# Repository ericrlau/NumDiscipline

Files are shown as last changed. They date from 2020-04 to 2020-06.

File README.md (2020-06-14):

# #DISCIPLINE (aka NumDiscipline)

A modified version of the great looking Discipline through hole keyboard design by coseyfannitutti to add numpad. 

## Modifications from original Discipline 

- Add numpad on right.
- Move arrow keys 0.25U down and right, similar to 1800 layout. 
- Adjust component layout on top of board, moving ATMega and buttons to the right, adding in more diodes in center. 
- Removed ~, Delete, Page Up, Page Down keys. These will be on alternate layer. 
- Created Digikey version of BOM, found here: https://octopart.com/bom-tool/AgAHKWUi

## ToDo 
- Adjust acrylic foot design to be wider, it looks a little thin. 
- add Via support
- Next order of PCBs: 
	- Adjust #DISCIPLINE logo in space bar area so that it doesn't overlap stablaizer. [Image](./images/knownIssues/Logoplacement.jpg)
	- Omit job number silk screen from vendor.[Plate](./images/knownIssues/plate.jpg) [Main](./images/knownIssues/jobNumMain.jpg) [Bottom](./images/knownIssues/jobNumBottom.jpg) 
	- Improve surface finish on black solder mask, some dark spots. [Image](./images/knownIssues/surfaceFinish.jpg) 
	- Remove drills from FR4 switch plate. [Image](./images/knownIssues/plate.jpg)

## Images

#### Prototype Build
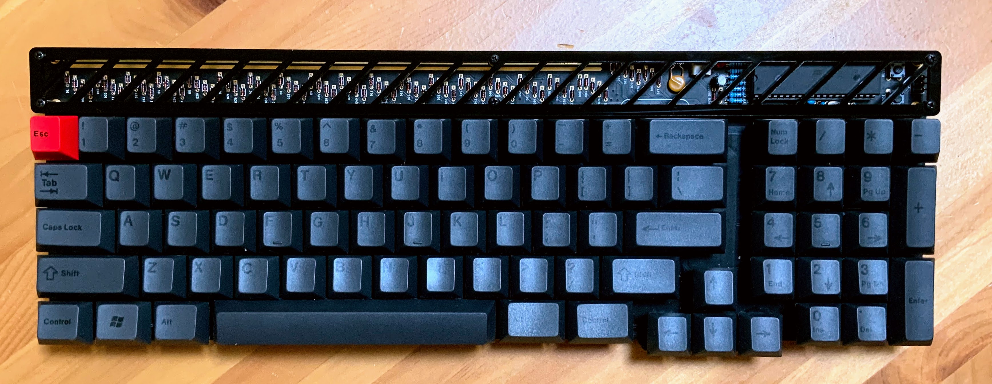
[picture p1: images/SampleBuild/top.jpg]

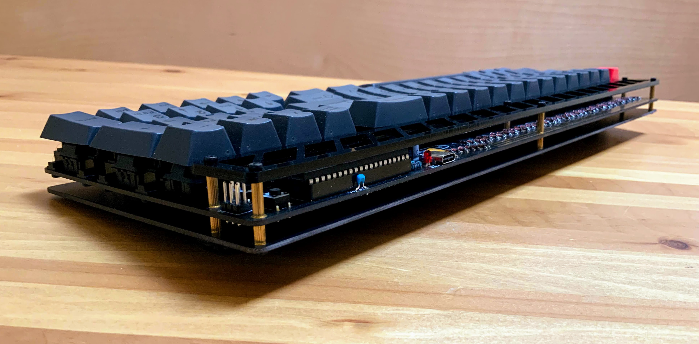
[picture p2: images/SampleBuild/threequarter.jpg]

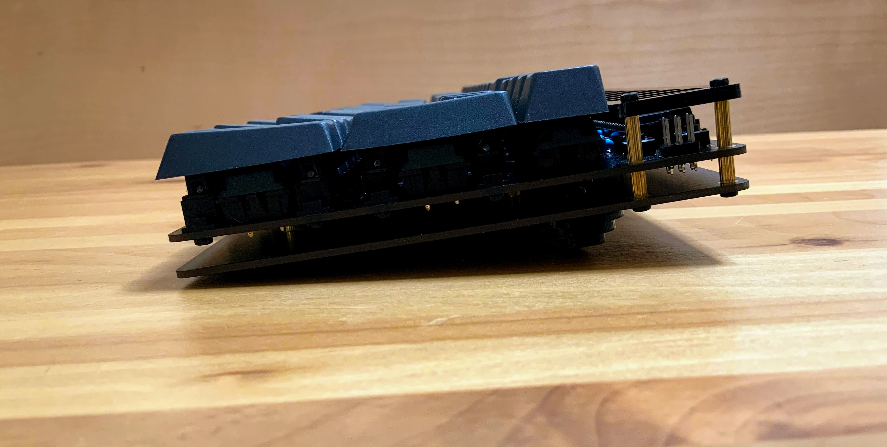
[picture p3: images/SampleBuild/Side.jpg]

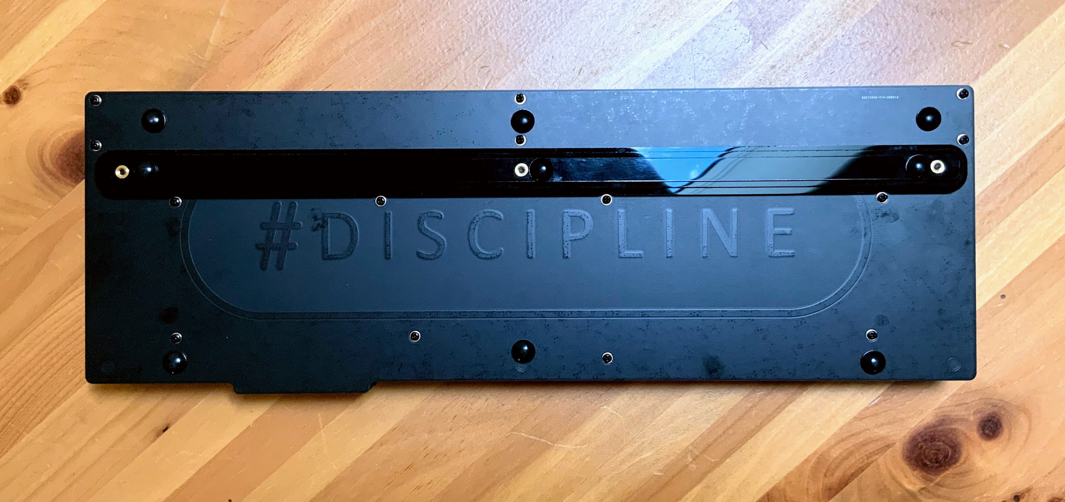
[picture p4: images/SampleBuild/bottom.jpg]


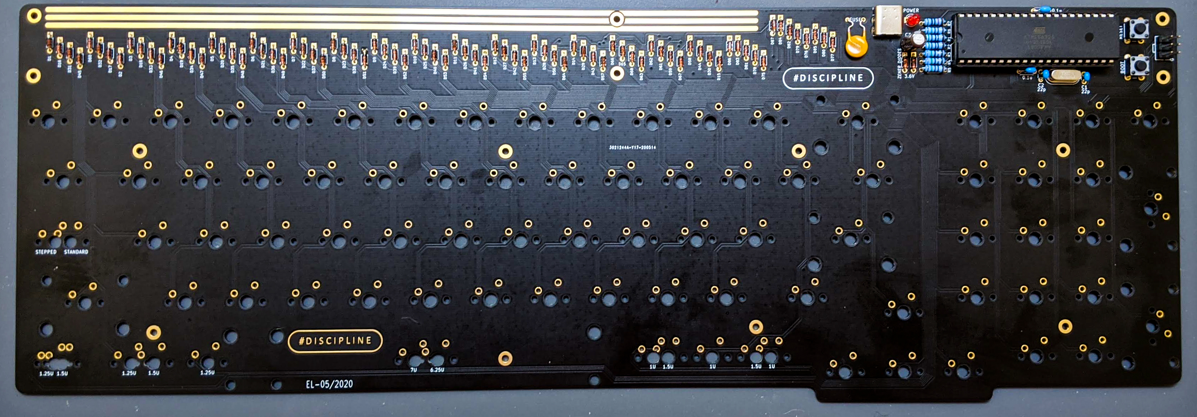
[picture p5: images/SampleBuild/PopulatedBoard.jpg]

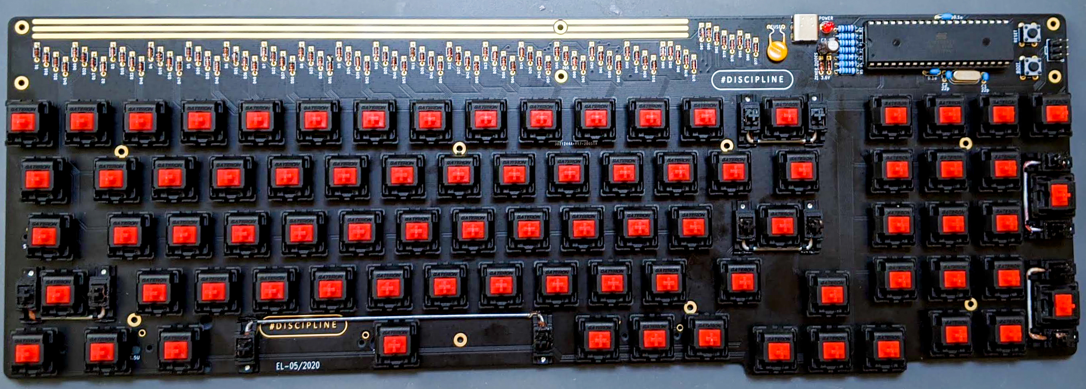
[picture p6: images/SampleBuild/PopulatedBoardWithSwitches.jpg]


#### Layout
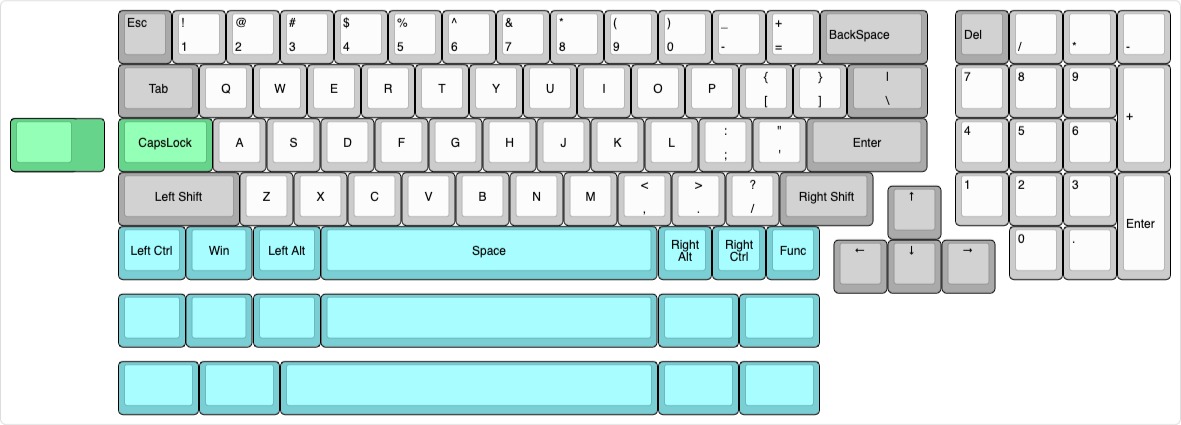
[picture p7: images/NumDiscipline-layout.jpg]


#### Main PCB
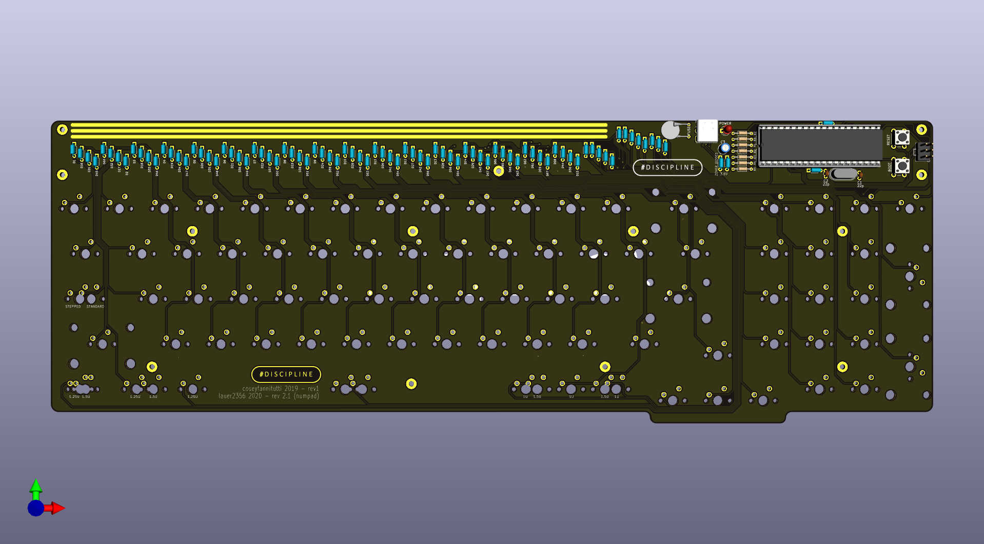
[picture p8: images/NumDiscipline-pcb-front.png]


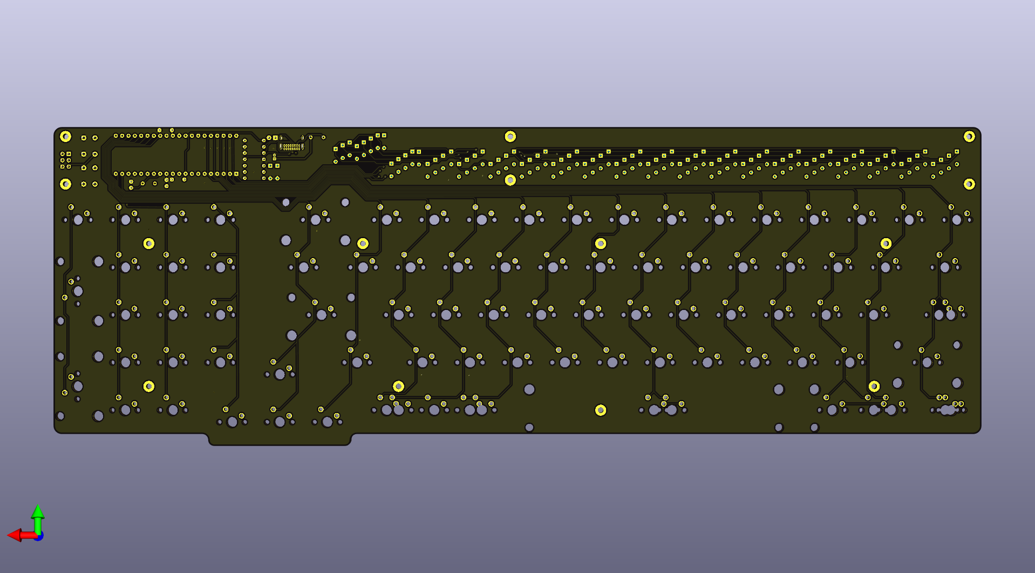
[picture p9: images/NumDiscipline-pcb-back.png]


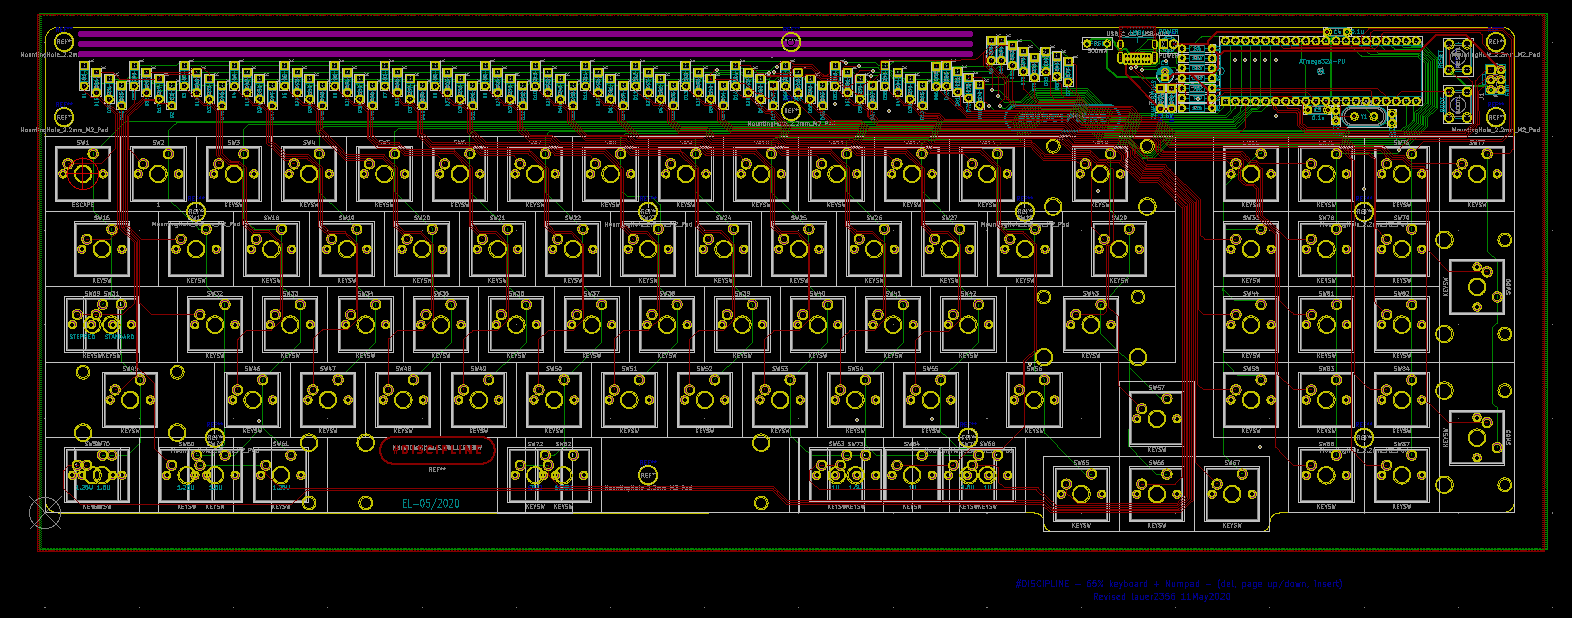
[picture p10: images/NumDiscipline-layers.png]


#### FR4 Plate
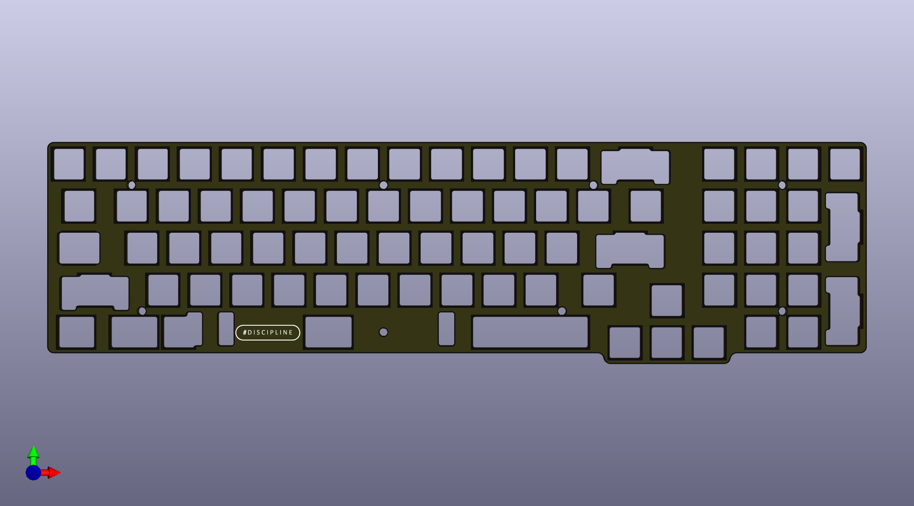
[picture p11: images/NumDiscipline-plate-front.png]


#### Bottom PCB
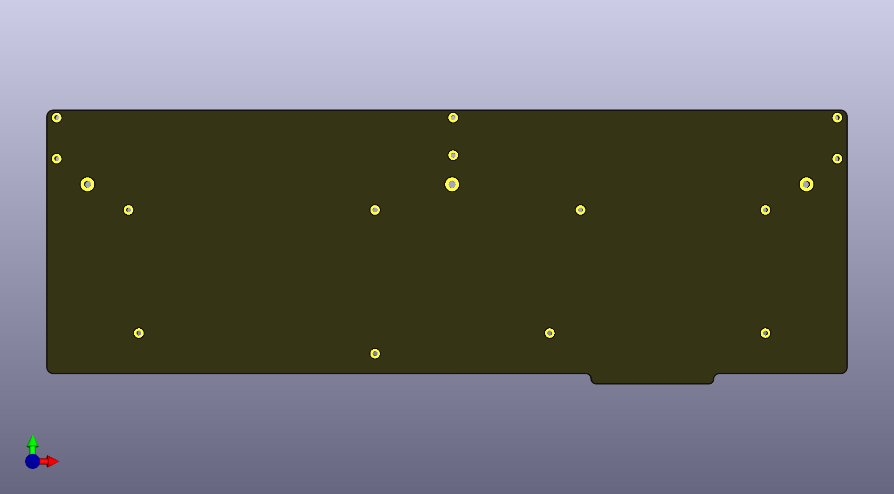
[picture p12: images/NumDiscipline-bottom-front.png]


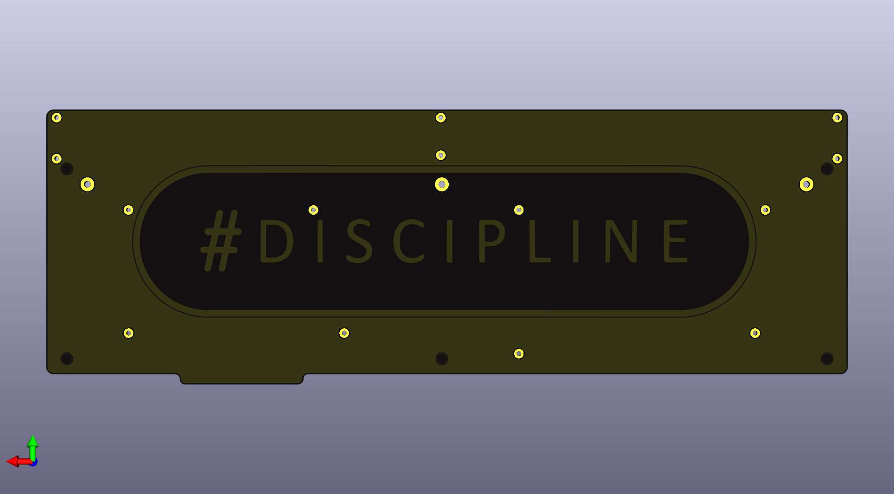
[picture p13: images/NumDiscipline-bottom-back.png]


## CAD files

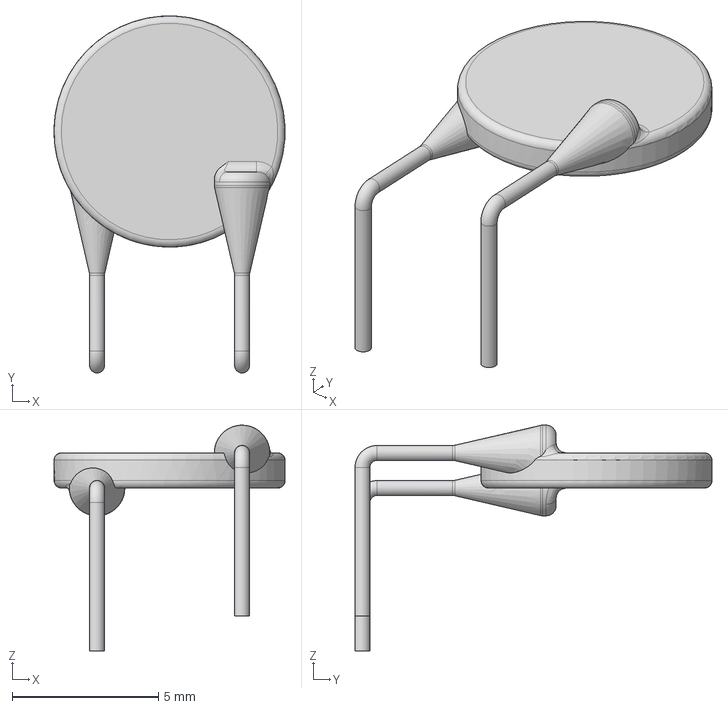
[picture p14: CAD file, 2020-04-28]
3d models/mf-r050_horizontal.step
7.90 x 12.2 x 7.72 mm

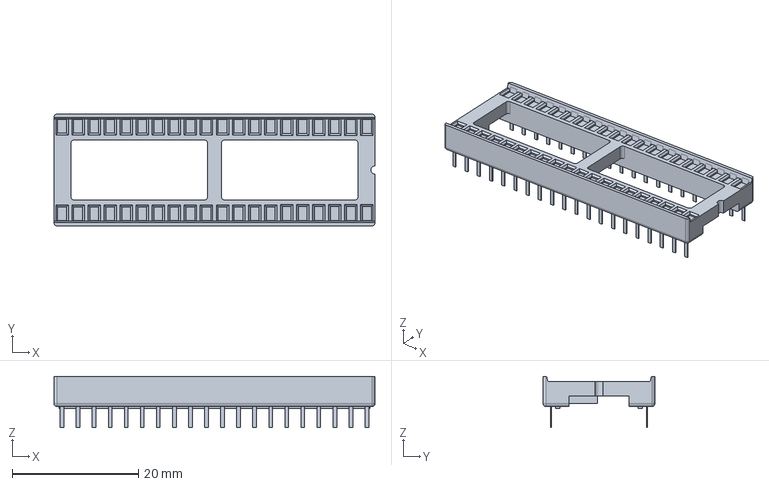
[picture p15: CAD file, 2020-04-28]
3d models/c-1-2199299-5-a-3d.stp
50.8 x 17.7 x 8.10 mm

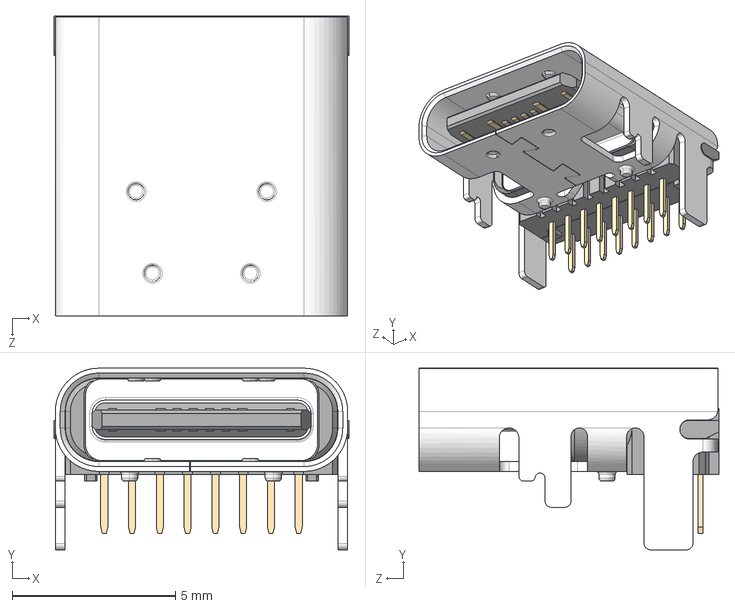
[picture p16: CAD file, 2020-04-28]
3d models/USB4085-GF-A_revA2.STEP
9.03 x 5.56 x 9.17 mm
housing_2

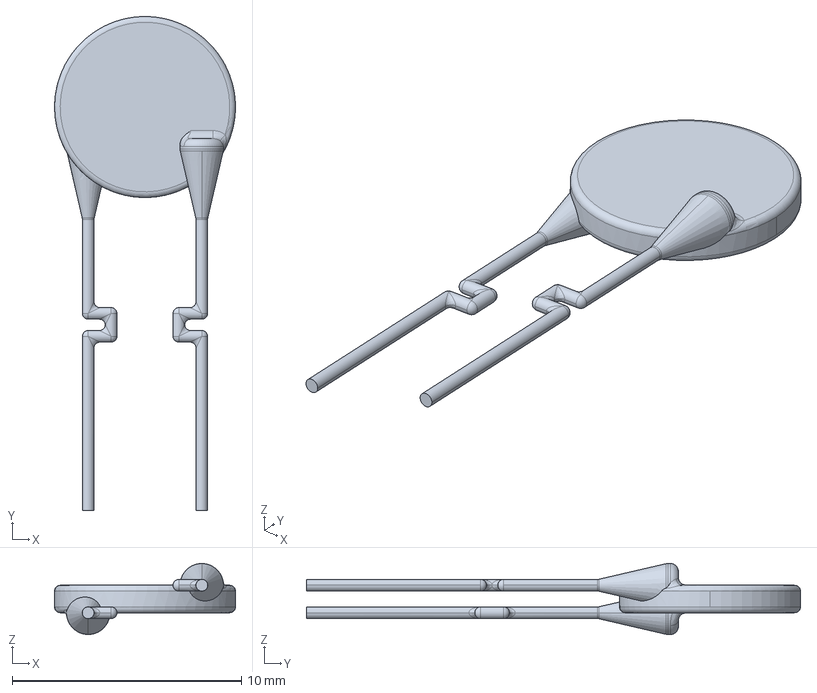
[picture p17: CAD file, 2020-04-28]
3d models/mf-r050.stp
7.90 x 21.6 x 3.10 mm

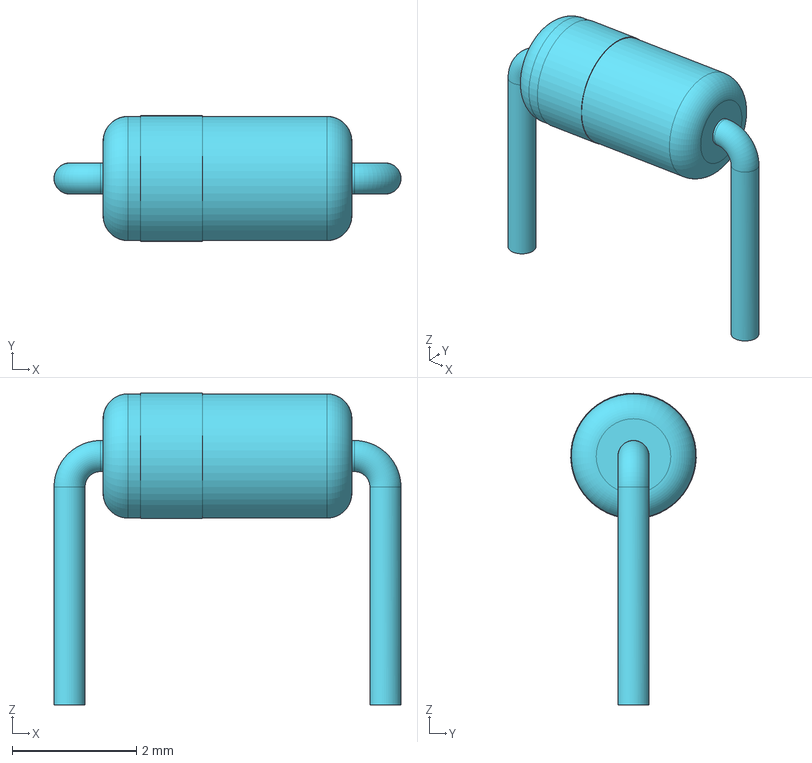
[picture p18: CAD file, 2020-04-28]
3d models/D_DO-35_SOD27_P5.08mm_Horizontal.step
5.58 x 2.02 x 5.01 mm

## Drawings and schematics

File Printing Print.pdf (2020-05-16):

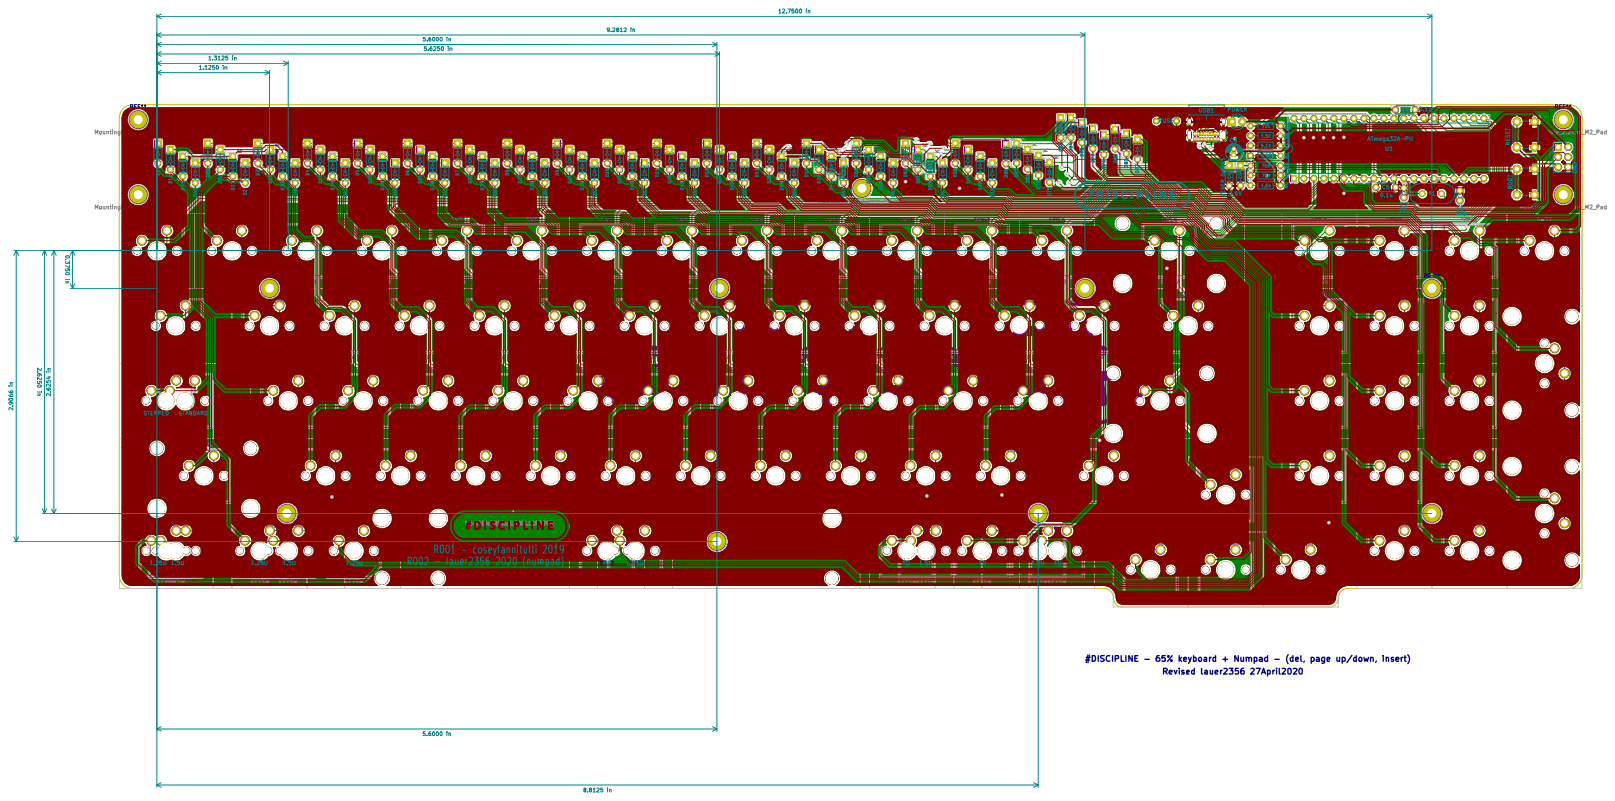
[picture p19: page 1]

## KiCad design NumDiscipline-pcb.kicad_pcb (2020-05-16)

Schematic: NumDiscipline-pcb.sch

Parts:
BOOT1: BOOT; SW_PUSH_6mm
C1, C2: 22p; C_Disc_D3.0mm_W1.6mm_P2.50mm
C3: 4.7u; CP_Radial_D4.0mm_P1.50mm
C4, C5: 0.1u; D_DO-35_SOD27_P5.08mm_Horizontal
D1, D2, D3, D4, D5, D6, D7, D8, D9, D10, D11, D12, D13, D14, D15, D16, D17, D18, D19, D20, D21, D22, D23, D24, D25, D26, D27, D28, D29, D30, D31, D32, D33, D34, D35, D36, D37, D38, D39, D40, D41, D42, D43, D44, D45, D46, D47, D48, D49, D50, D51, D52, D53, D54, D55, D56, D57, D58, D59, D60, D61, D62, D63, D64, D65, D66, D67, D68, D75, D76, D77, D78, D79, D80, D81, D82, D83, D84, D85, D86, D87: D_DO-35_SOD27_P5.08mm_Horizontal
D69, D70: 3.6V; D_DO-35_SOD27_P5.08mm_Horizontal
F1: 500mA; polyfuse_5.1mm
J1: AVR-ISP-6; AVR_ICSP_3x2
LED1: POWER; LED_D3.0mm
R1, R2: 5.1k; R_Axial_DIN0204_L3.6mm_D1.6mm_P7.62mm_Horizontal
R3, R4: 75R; R_Axial_DIN0204_L3.6mm_D1.6mm_P7.62mm_Horizontal
R5: 1.5k; R_Axial_DIN0204_L3.6mm_D1.6mm_P7.62mm_Horizontal
R6: 1.5K; R_Axial_DIN0204_L3.6mm_D1.6mm_P7.62mm_Horizontal
R7: 10k; R_Axial_DIN0204_L3.6mm_D1.6mm_P7.62mm_Horizontal
RESET1: RESET; SW_PUSH_6mm
SW1: ESCAPE; SW_Cherry_MX1A_1.00u_PCB-NOSCREEN
SW2: 1; SW_Cherry_MX1A_1.00u_PCB-NOSCREEN
SW3, SW4, SW5, SW6, SW7, SW8, SW9, SW10, SW11, SW12, SW13, SW15, SW17, SW18, SW19, SW20, SW21, SW22, SW23, SW24, SW25, SW26, SW27, SW28, SW30, SW32, SW33, SW34, SW35, SW36, SW37, SW38, SW39, SW40, SW41, SW42, SW44, SW46, SW47, SW48, SW49, SW50, SW51, SW52, SW53, SW54, SW55, SW57, SW58, SW62, SW65, SW66, SW67, SW68, SW72, SW75, SW76, SW77, SW78, SW79, SW81, SW82, SW83, SW84, SW86, SW87: KEYSW; SW_Cherry_MX1A_1.00u_PCB-NOSCREEN
SW14, SW80, SW85: KEYSW; SW_Cherry_MX1A_2.00u_PCBNOSCREEN
SW16, SW29, SW70, SW71, SW73, SW74: KEYSW; SW_Cherry_MX1A_1.50u_PCBNOSCREEN
SW31, SW56: KEYSW; SW_Cherry_MX1A_1.75u_PCBNOSCREEN
SW43, SW45: KEYSW; SW_Cherry_MX1A_2.25u_PCBNOSCREEN
SW59, SW60, SW61, SW63, SW64, SW69: KEYSW; SW_Cherry_MX1A_1.25u_PCBNOSCREEN
U1: ATmega32A-PU; DIP-40_W15.24mm
USB1: USB_C_GCT_USB4085
Y1: Crystal; Crystal_HC49-4H_Vertical

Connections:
+5V: C3.1, C4.1, C5.1, F1.1, J1.2, LED1.2 (A), R5.1, R7.1, U1.10, U1.30
D+: R4.1, U1.16
D-: R3.1, U1.17
GND: BOOT1.1, C1.2, C2.2, C3.2, C4.2, C5.2, D69.2 (A), D70.2 (A), J1.6, R1.1, R2.2, R6.2, RESET1.1, U1.11, U1.31, USB1.A1, USB1.A12, USB1.B1, USB1.B12, USB1.S1
MISO: J1.1, U1.7
MOSI: J1.4, U1.6
unnamed: C1.1, U1.13, Y1.1
unnamed: C2.1, U1.12, Y1.2
unnamed: D1.2 (A), SW1.2
unnamed: D2.2 (A), SW2.2
unnamed: D3.2 (A), SW3.2
unnamed: D4.2 (A), SW4.2
unnamed: D5.2 (A), SW5.2
unnamed: D6.2 (A), SW6.2
unnamed: D7.2 (A), SW7.2
unnamed: D8.2 (A), SW8.2
unnamed: D9.2 (A), SW9.2
unnamed: D10.2 (A), SW10.2
unnamed: D11.2 (A), SW11.2
unnamed: D12.2 (A), SW12.2
unnamed: D13.2 (A), SW13.2
unnamed: D14.2 (A), SW14.2
unnamed: D15.2 (A), SW15.2
unnamed: D16.2 (A), SW16.2
unnamed: D17.2 (A), SW17.2
unnamed: D18.2 (A), SW18.2
unnamed: D19.2 (A), SW19.2
unnamed: D20.2 (A), SW20.2
unnamed: D21.2 (A), SW21.2
unnamed: D22.2 (A), SW22.2
unnamed: D23.2 (A), SW23.2
unnamed: D24.2 (A), SW24.2
unnamed: D25.2 (A), SW25.2
unnamed: D26.2 (A), SW26.2
unnamed: D27.2 (A), SW27.2
unnamed: D28.2 (A), SW28.2
unnamed: D29.2 (A), SW29.2
unnamed: D30.2 (A), SW30.2
unnamed: D31.2 (A), SW31.2, SW69.2
unnamed: D32.2 (A), SW32.2
unnamed: D33.2 (A), SW33.2
unnamed: D34.2 (A), SW34.2
unnamed: D35.2 (A), SW35.2
unnamed: D36.2 (A), SW36.2
unnamed: D37.2 (A), SW37.2
unnamed: D38.2 (A), SW38.2
unnamed: D39.2 (A), SW39.2
unnamed: D40.2 (A), SW40.2
unnamed: D41.2 (A), SW41.2
unnamed: D42.2 (A), SW42.2
unnamed: D43.2 (A), SW43.2
unnamed: D44.2 (A), SW44.2
unnamed: D45.2 (A), SW45.2
unnamed: D46.2 (A), SW46.2
unnamed: D47.2 (A), SW47.2
unnamed: D48.2 (A), SW48.2
unnamed: D49.2 (A), SW49.2
unnamed: D50.2 (A), SW50.2
unnamed: D51.2 (A), SW51.2
unnamed: D52.2 (A), SW52.2
unnamed: D53.2 (A), SW53.2
unnamed: D54.2 (A), SW54.2
unnamed: D55.2 (A), SW55.2
unnamed: D56.2 (A), SW56.2
unnamed: D57.2 (A), SW57.2
unnamed: D58.2 (A), SW58.2
unnamed: D59.2 (A), SW59.2, SW70.2
unnamed: D60.2 (A), SW60.2
unnamed: D61.2 (A), SW61.2, SW71.2
unnamed: D62.2 (A), SW62.2, SW72.2
unnamed: D63.2 (A), SW63.2, SW73.2
unnamed: D64.2 (A), SW64.2, SW74.2
unnamed: D65.2 (A), SW65.2
unnamed: D66.2 (A), SW66.2
unnamed: D67.2 (A), SW67.2
unnamed: D68.2 (A), SW68.2
unnamed: D69.1 (K), R3.2, R5.2, USB1.A7, USB1.B7
unnamed: D70.1 (K), R4.2, USB1.A6, USB1.B6
unnamed: D75.2 (A), SW75.2
unnamed: D76.2 (A), SW76.2
unnamed: D77.2 (A), SW77.2
unnamed: D78.2 (A), SW78.2
unnamed: D79.2 (A), SW79.2
unnamed: D80.2 (A), SW80.2
unnamed: D81.2 (A), SW81.2
unnamed: D82.2 (A), SW82.2
unnamed: D83.2 (A), SW83.2
unnamed: D84.2 (A), SW84.2
unnamed: D85.2 (A), SW85.2
unnamed: D86.2 (A), SW86.2
unnamed: D87.2 (A), SW87.2
unnamed: LED1.1 (K), R6.1
unnamed: R1.2, USB1.A5
unnamed: R2.1, USB1.B5
SCK: J1.3, U1.8
VCC: F1.2, USB1.A4, USB1.A9, USB1.B4, USB1.B9
boot: BOOT1.2, U1.18
col0: SW1.1, SW16.1, SW31.1, SW45.1, SW59.1, SW69.1, SW70.1, U1.38
col1: SW2.1, SW17.1, SW32.1, SW60.1, U1.4
col2: SW3.1, SW18.1, SW33.1, SW46.1, SW61.1, SW71.1, U1.37
col3: SW4.1, SW19.1, SW34.1, SW47.1, U1.5
col4: SW5.1, SW20.1, SW35.1, SW48.1, U1.36
col5: SW6.1, SW21.1, SW36.1, SW49.1, U1.19
col6: SW7.1, SW22.1, SW37.1, SW50.1, SW62.1, SW72.1, U1.20
col7: SW8.1, SW23.1, SW38.1, SW51.1, U1.28
col8: SW9.1, SW24.1, SW39.1, SW52.1, U1.27
col9: SW10.1, SW25.1, SW40.1, SW53.1, SW63.1, SW73.1, U1.26
col10: SW11.1, SW26.1, SW41.1, SW54.1, SW64.1, SW74.1, U1.25
col11: SW12.1, SW27.1, SW42.1, SW55.1, SW68.1, U1.24
col12: SW13.1, SW28.1, SW56.1, SW65.1, U1.23
col13: SW14.1, SW29.1, SW43.1, SW57.1, SW66.1, U1.22
col14: SW15.1, SW30.1, SW44.1, SW58.1, SW67.1, U1.21
col15: SW75.1, SW78.1, SW81.1, SW83.1, SW86.1, U1.35
col16: SW76.1, SW79.1, SW82.1, SW84.1, SW87.1, U1.34
col17: SW77.1, SW80.1, SW85.1, U1.33
reset: J1.5, R7.2, RESET1.2, U1.9
row0: D1.1 (K), D2.1 (K), D3.1 (K), D4.1 (K), D5.1 (K), D6.1 (K), D7.1 (K), D8.1 (K), D9.1 (K), D10.1 (K), D11.1 (K), D12.1 (K), D13.1 (K), D14.1 (K), D15.1 (K), D75.1 (K), D76.1 (K), D77.1 (K), U1.3
row1: D16.1 (K), D17.1 (K), D18.1 (K), D19.1 (K), D20.1 (K), D21.1 (K), D22.1 (K), D23.1 (K), D24.1 (K), D25.1 (K), D26.1 (K), D27.1 (K), D28.1 (K), D29.1 (K), D30.1 (K), D78.1 (K), D79.1 (K), D80.1 (K), U1.39
row2: D31.1 (K), D32.1 (K), D33.1 (K), D34.1 (K), D35.1 (K), D36.1 (K), D37.1 (K), D38.1 (K), D39.1 (K), D40.1 (K), D41.1 (K), D42.1 (K), D43.1 (K), D44.1 (K), D81.1 (K), D82.1 (K), U1.2
row3: D45.1 (K), D46.1 (K), D47.1 (K), D48.1 (K), D49.1 (K), D50.1 (K), D51.1 (K), D52.1 (K), D53.1 (K), D54.1 (K), D55.1 (K), D56.1 (K), D57.1 (K), D58.1 (K), D83.1 (K), D84.1 (K), D85.1 (K), U1.40
row4: D59.1 (K), D60.1 (K), D61.1 (K), D62.1 (K), D63.1 (K), D64.1 (K), D65.1 (K), D66.1 (K), D67.1 (K), D68.1 (K), D86.1 (K), D87.1 (K), U1.1

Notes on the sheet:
DISCIPLINE // 65% keyboard with only through hole components
7/1/2019
DISCIPLINE

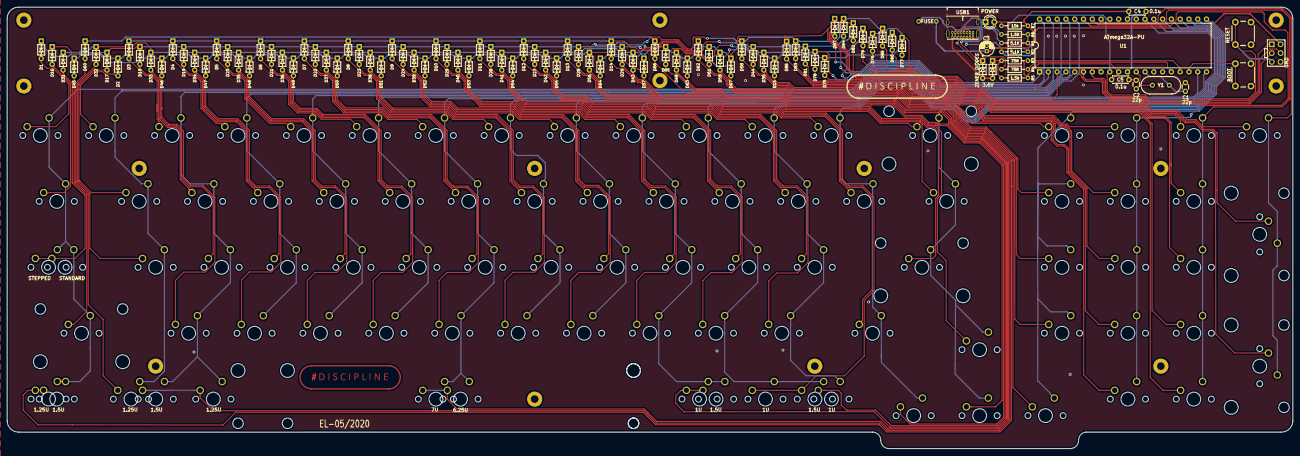
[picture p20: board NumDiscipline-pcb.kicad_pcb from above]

Board: 2 copper layers, 371.6 x 127.6 mm, 191 parts (0 on the bottom side), 121 nets.

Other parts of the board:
ST62: 7U; MX-7U-Stabilizer

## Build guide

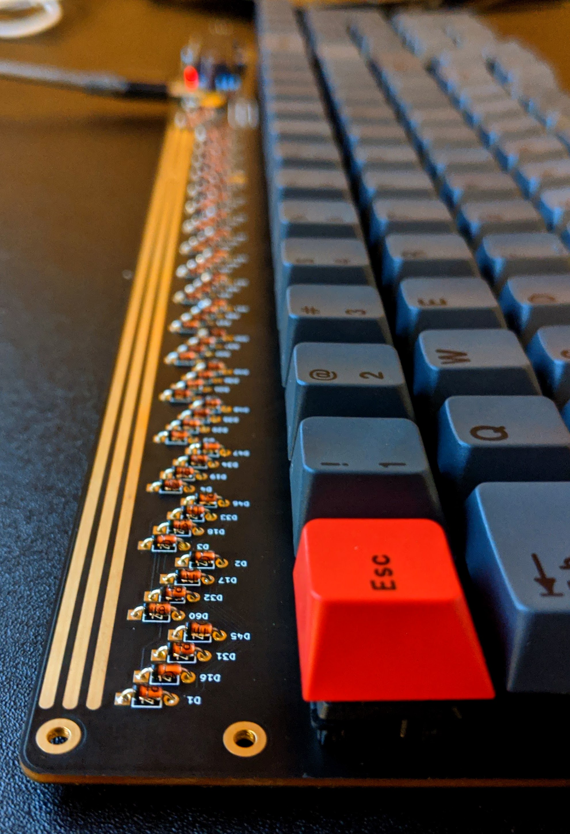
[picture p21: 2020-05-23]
images/SampleBuild/proto2_detail.jpg

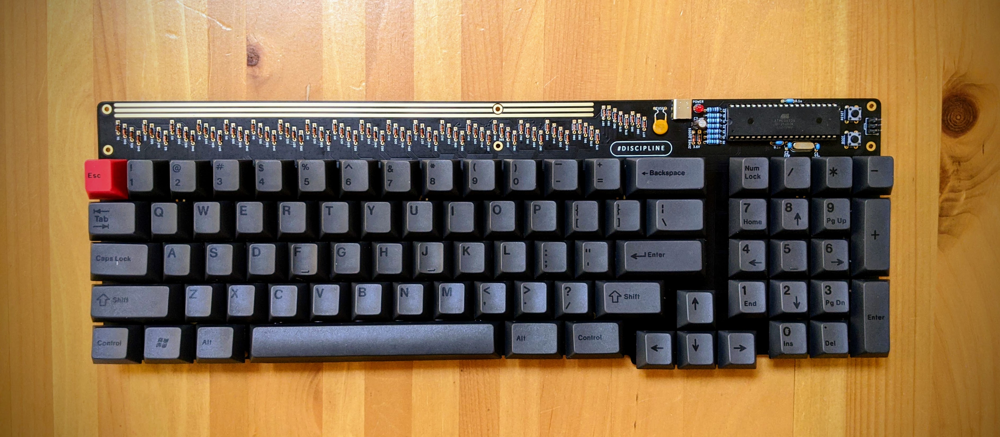
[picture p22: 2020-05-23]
images/SampleBuild/proto2.jpg

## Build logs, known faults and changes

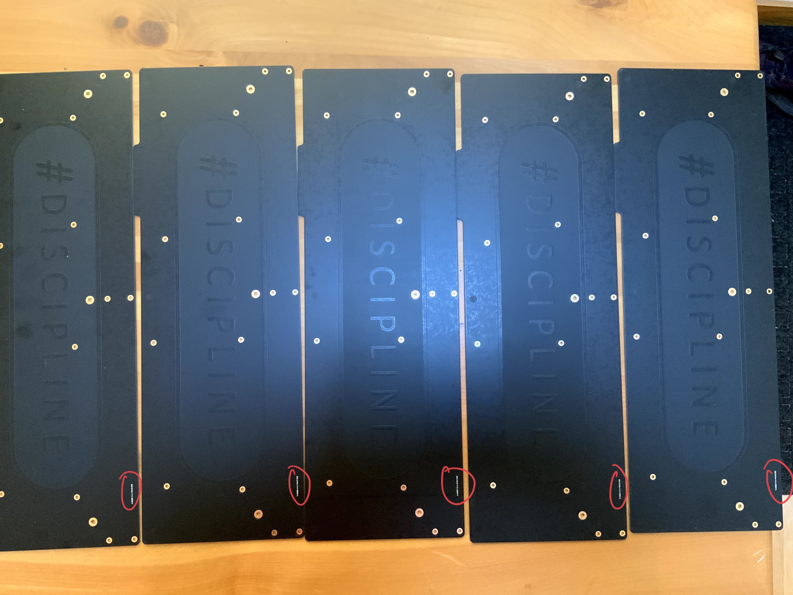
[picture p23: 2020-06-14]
images/knownIssues/jobNumBottom.jpg

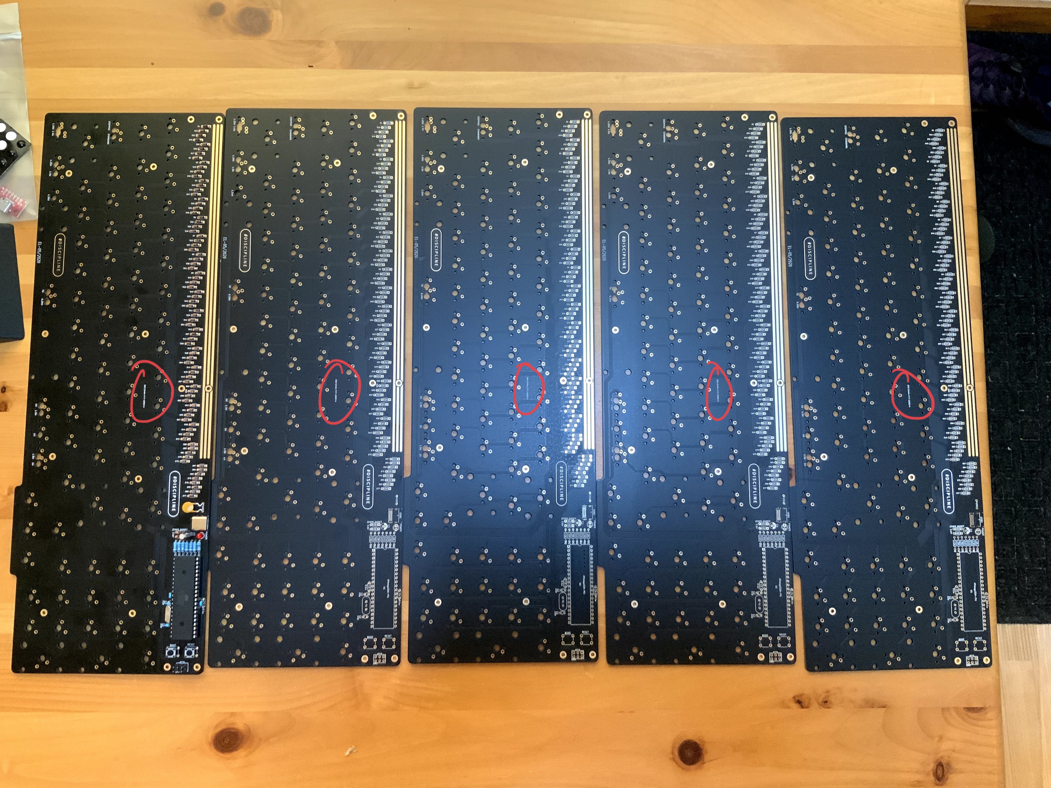
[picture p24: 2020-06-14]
images/knownIssues/jobNumMain.jpg

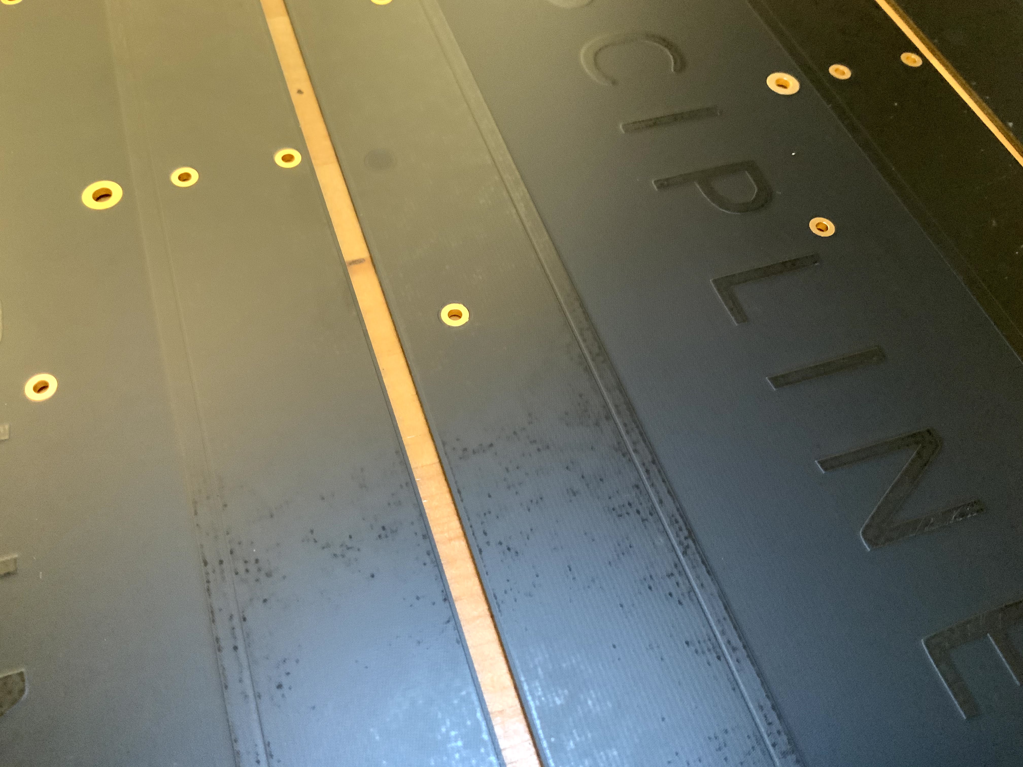
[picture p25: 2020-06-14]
images/knownIssues/surfaceFinish.jpg

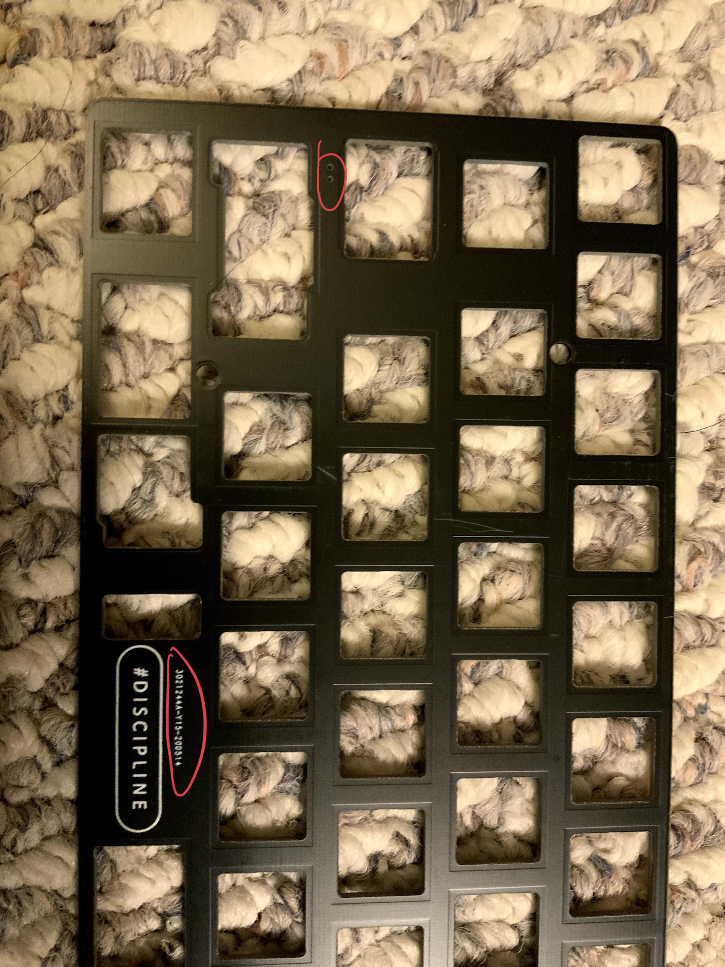
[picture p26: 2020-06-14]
images/knownIssues/plate.jpg

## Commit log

2020-04-26 initial commit from discipline
    [acrylic-guard.dxf, discipline-bottom.dxf, discipline-closed-layer.dxf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]
2020-04-26 added numpad to pcb, still need layout updates
    [discipline-pcb.kicad_pcb, discipline-pcb.sch]
2020-04-27 working on routing, renamed project file
    [NumDiscipline-pcb.kicad_pcb, NumDiscipline-pcb.sch, discipline-pcb.kicad_pcb]
2020-04-27 new routing fixed, ready for checkover
    [NumDiscipline-pcb.kicad_pcb]
2020-04-28 add plate
    [FR4Plate.kicad_pcb, FR4Plate.sch, NumDiscipline-pcb.kicad_pcb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]
2020-04-28 add 3d, finish plate
    [D_DO-35_SOD27_P5.08mm_Horizontal.step, FR4Plate.kicad_pcb, NumDiscipline-pcb.kicad_pcb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]
2020-04-30 cleanup files, update readme, add gerbers
    [FR4Plate-B_Cu.gbr, FR4Plate-B_Mask.gbr, FR4Plate-B_Paste.gbr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]
2020-05-11 start making adjustments from first proto
    [FR4Plate.kicad_pcb, NumDiscipline-pcb.kicad_pcb, NumDiscipline-pcb.sch]
2020-05-12 proto feedback incorperated
    [FR4Plate-B_Cu.gbr, FR4Plate-B_Mask.gbr, FR4Plate-B_Paste.gbr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]
2020-05-14 order PCBs and ponoko
    [FR4 Plate - TopFoam.dxf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]
2020-05-23 update readme after sample build
2020-05-23 add drill note on FR4 plate in readme
2020-06-14 remove old dxg files, new ones coming soon
    [FR4 Plate - TopFoam.dxf, Foam and Guard - 6mm FOam.dxf, Foam and Guard - AcrylicGaurd.dxf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]
